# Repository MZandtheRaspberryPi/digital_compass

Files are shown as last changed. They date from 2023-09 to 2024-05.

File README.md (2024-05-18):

# digital_compass
Firmware, cad, and documentation for my digital compass project. This is a project where I designed, manufactured, and coded a digital compass that uses an inertial measurement unit (IMU) to estimate orientation in 3d-space. I implemented an extended kalman filter to (EKF) to do the estimation. A video explanation is available [here](https://www.youtube.com/shorts/Pg_2u4VAHLg) and a video demo is available [here](https://www.youtube.com/shorts/pv6mBfAY-nU).  

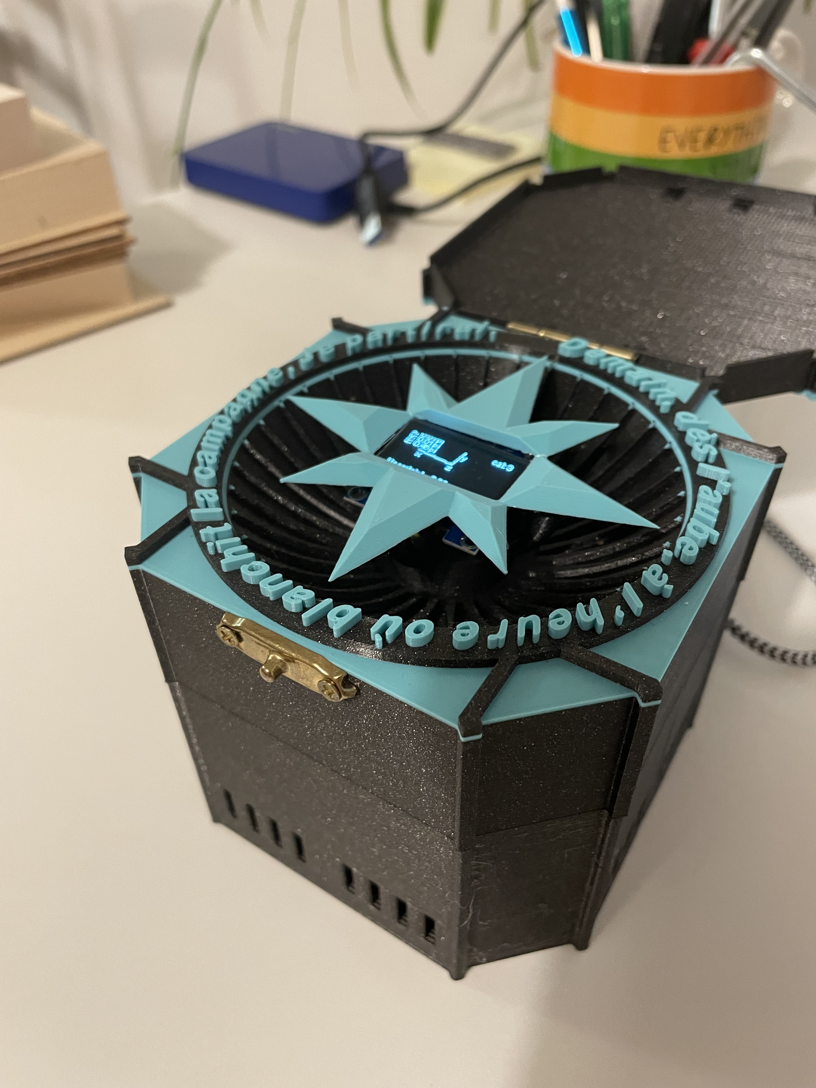
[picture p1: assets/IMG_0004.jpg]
compass_pic

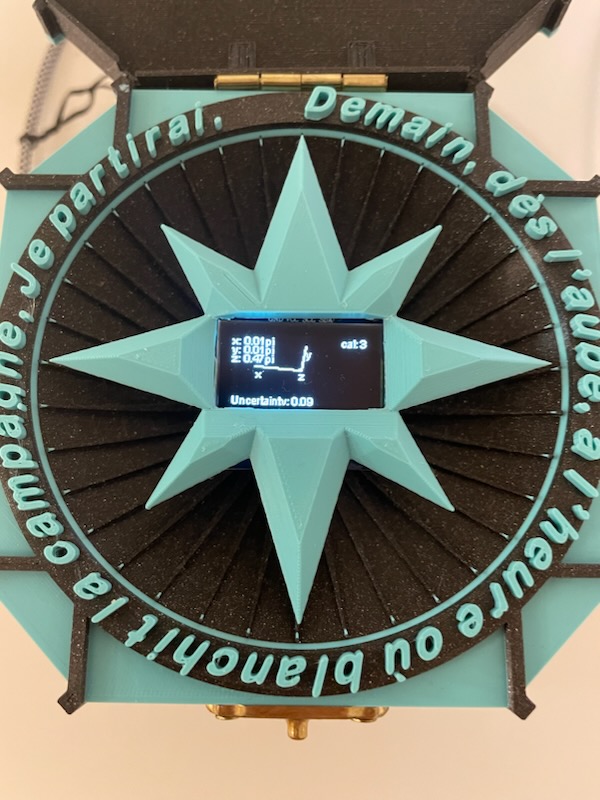
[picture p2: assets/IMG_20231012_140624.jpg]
compass_pic_2
  
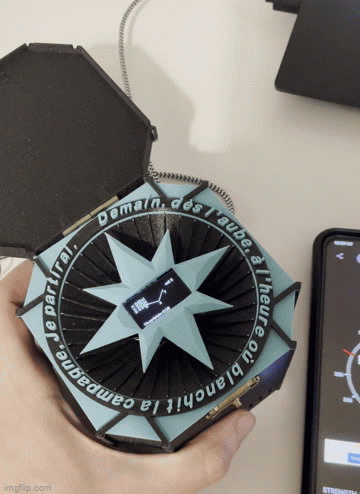
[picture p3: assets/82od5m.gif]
compass_demo
  

### Software  
On the software side I separated the project broadly into 3 components:  
* publishing the measurements from the sensor
* estimating orientation from the measurements
* visualizing the orientation  
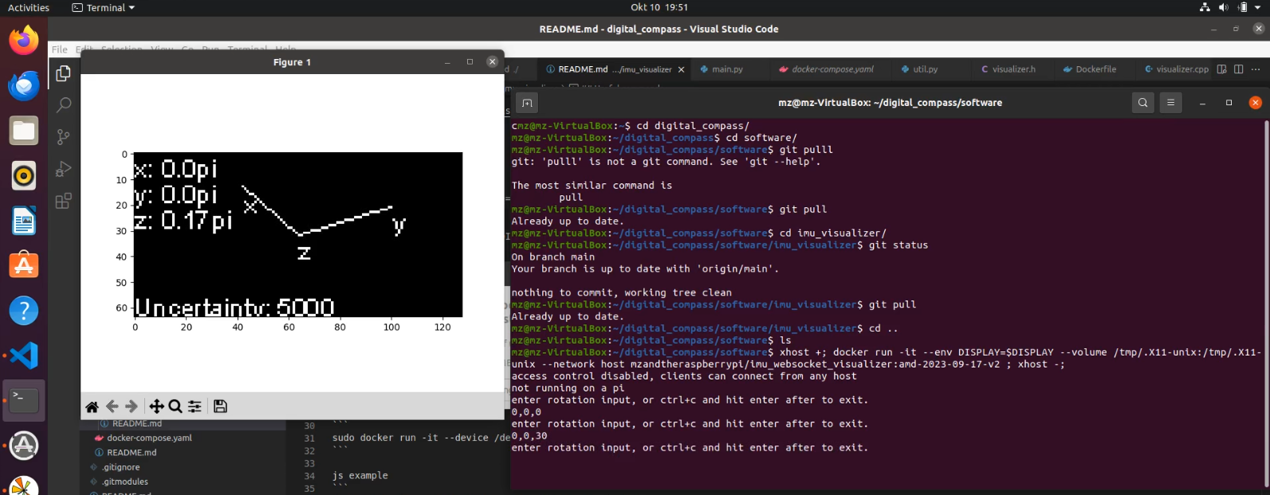
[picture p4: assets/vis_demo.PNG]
visualizer_demo


Design considerations:
* modular.
* shared libraries for websockets and message serialization.
* mainly c++.
* for matrix operations compile time checking of dimensions.
* only recreate the wheel for the filter algorithm, for the rest use libraries.
* for filter algorithm, make it possible to try different system models (expanding state matrix to estimate position for example) as well as different filter algorithms (UKF, particle filter, for example). Enter templates.  

To help keep things modular I used docker where each of the 3 components ran in a docker container. They talked to each other through websockets and messages serialized using Google's protobuffer. I used mainly CMake as a build system.  

You can run the package by navigating to the software sub directory and using docker compose to launch the compass.  

On libraries I created:  
* imu_broadcaster -- a repo that talks to the sensor and publishes calibration information, bosch's estimates of orientation, linear acceleration, angular acceleration, magnetic vector, timestamps, and more [here](https://github.com/MZandtheRaspberryPi?tab=repositories).
* imu_filter_cpp -- a repo that implements the system model and an Extended Kalman Filter to estimate orientation from the sensor data and publishes this onward [here](https://github.com/MZandtheRaspberryPi/imu_filter_cpp).
* imu_visualizer -- a repo that listens to our orientation estimate and visualies this on the screen inside of the compass. It projects the 3d coordinate frame onto the 2d screen [here](https://github.com/MZandtheRaspberryPi/imu_visualizer).
* imu_websockets -- a repo that contains wrappers for the third party websocketpp library to easily broadcast and listen, as well as our protobuffer message files and generated libraries [here](https://github.com/MZandtheRaspberryPi/imu_websockets).  
* imu_filter -- a repo to use imu data and ground truth data [[2]](#2) and simulate our model as a proof of concept [here](https://github.com/MZandtheRaspberryPi/imu_filter).
* Adafruit_BNO055 -- a repo I forked from Adafruit's implementation (see below in 3rd party library section) but heavily modified to build using CMake and to run on a raspberry pi instead of an Arduino board [here](https://github.com/MZandtheRaspberryPi/Adafruit_BNO055).  
* imu_adafruit_testing -- a repo to do initial tests that we can get sensor data in docker using some adafruit libraries and using 2 sensors [here](https://github.com/MZandtheRaspberryPi/imu_adafruit_testing).

On third party libraries used:  
* the Eigen3 Library and their Eigen::Matrix class to do linear algebra [here](https://eigen.tuxfamily.org/index.php?title=Main_Page).
* the websocketspp library to setup and send data using websockets [here](https://eigen.tuxfamily.org/index.php?title=Main_Page).
* adafruit libraries to talk to the Adafruit bno055 sensor dev board I used, namely the Adafruit_BNO055 library [here](https://github.com/adafruit/Adafruit_BNO055), though I heavily modified it to run on a raspberry pi instead of an Arduino board. Also the adafruit-circuitpython-ssd1306 library to write to the oled.
* the libi2c-dev ubuntu library to talk to my sensor [here](https://packages.ubuntu.com/jammy/libi2c-dev).

To run this, I used the docker compose file [here](software/docker-compose.yaml).  
```
docker compose up
```

Or you could add something like the below to your cronjobs:
```
@reboot sleep 30; /usr/bin/docker compose -f /home/mikey/digital_compass/software/docker-compose.yaml up
```

### Design and Manufacturing

I designed the compass using Fusion 360 to look nice, be easily be assembled and disassembled, and be 3d printable. You can find design files in the cad_and_ecad folder.  

Here are some renders I made using Fusion 360 of the CAD:  

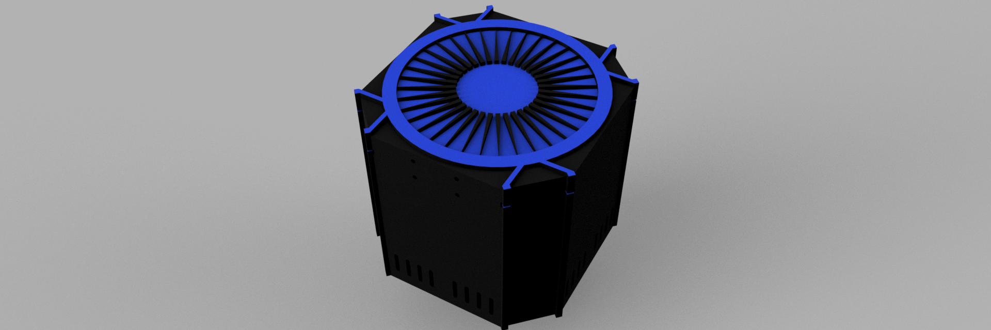
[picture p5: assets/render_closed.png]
body_render_closed


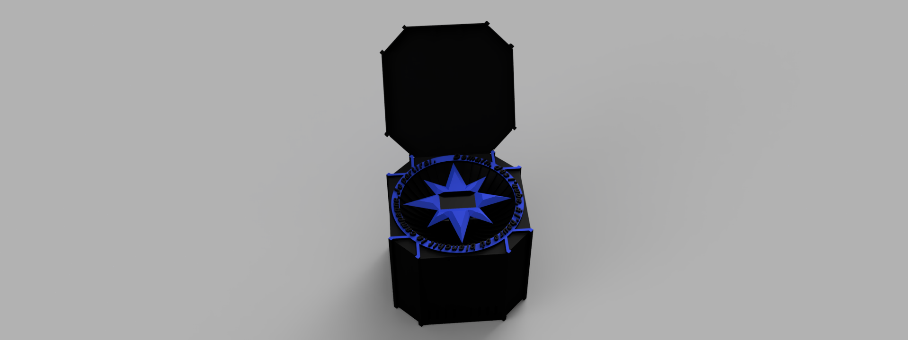
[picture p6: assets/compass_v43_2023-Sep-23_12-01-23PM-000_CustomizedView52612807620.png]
body_render


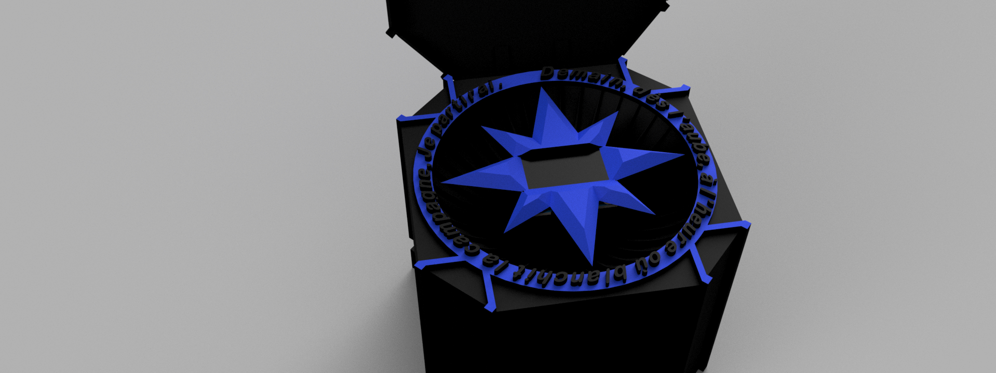
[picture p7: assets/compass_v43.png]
body_render_zoomed
  

The design uses threaded inserts to make it easy to assemble and take apart. It also uses a metal brass hinge for the top cover.  

One fun bit was trying to design a part to hold the screen. I wanted a super low profile, and so came up with a design inspired by an alien octopus grabbing the screen cover in a couple places with tentacle arms.  
screen_cover_1
screen_cover

I also ended up desiging a custom printed circuit board to simplify wiring. Before the custom PCB:  

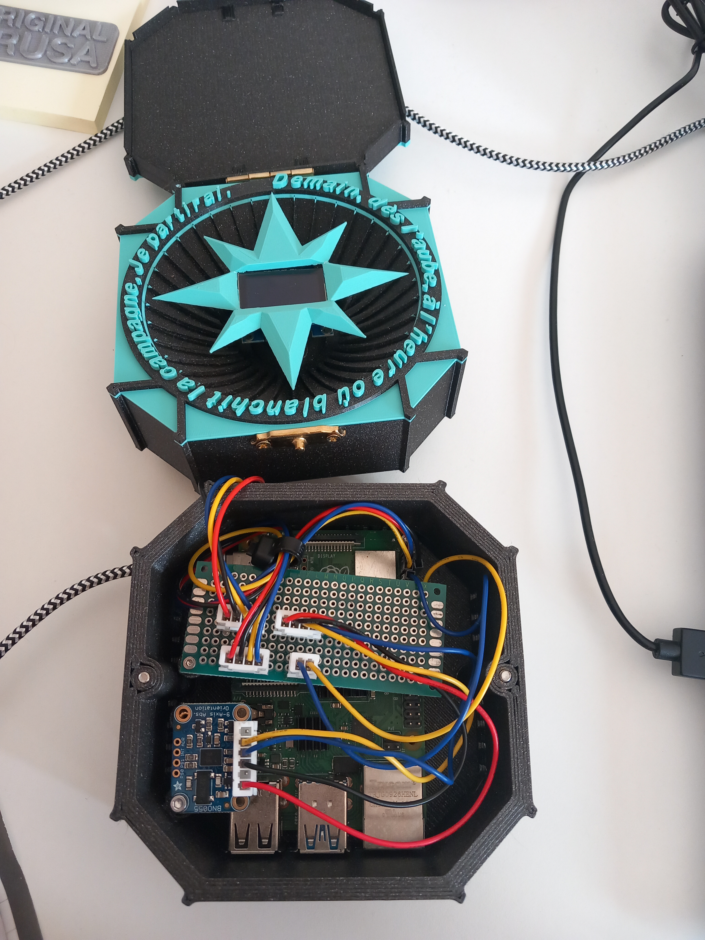
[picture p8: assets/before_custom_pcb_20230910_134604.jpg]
  

And after:  
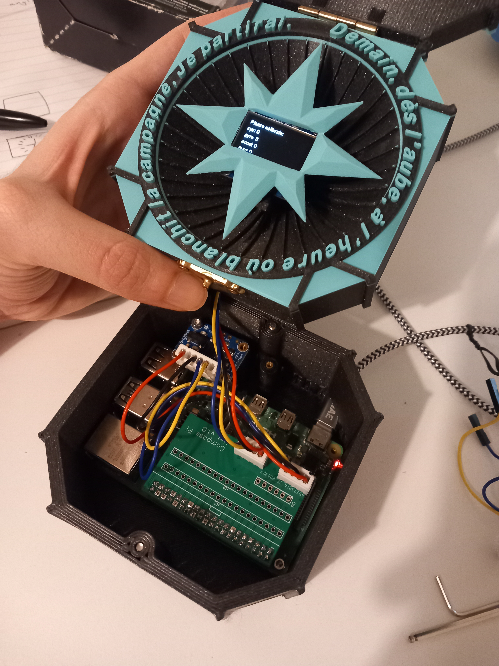
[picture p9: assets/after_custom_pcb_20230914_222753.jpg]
  

On the 3d Printing I used multi-color printing by doing a color change at a certain layer. With this I was able to get accent colors I quite liked.

### Maths
A big part of this project was modelling a system that could take measurements from an inertial measurement unit including angular rotation, linear acceleration, and magnetic vector, and estimate orientation. For this, I implemented a model from a 2020 paper by Saito et al, [[1]](#1),  with minimal tweaks. This was actually the first thing I did in this project, where I worked in simulation for some time till I thought I could pull it off in real life. You can see more details in the maths subdirectory and the .pdf write up in that directory [here](https://github.com/MZandtheRaspberryPi/imu_filter/blob/main/write_up/project_writeup.pdf), but briefly I found some data from an IMU including ground truth data [here](https://github.com/agnieszkaszczesna/RepoIMU) [[2]](#2) and played this back in simulation and implemented a model to try and match the ground truth data given sensor measurements. You can see this simulation output below, where it is not perfect and it jumps sometimes, but it is not worlds apart either:  
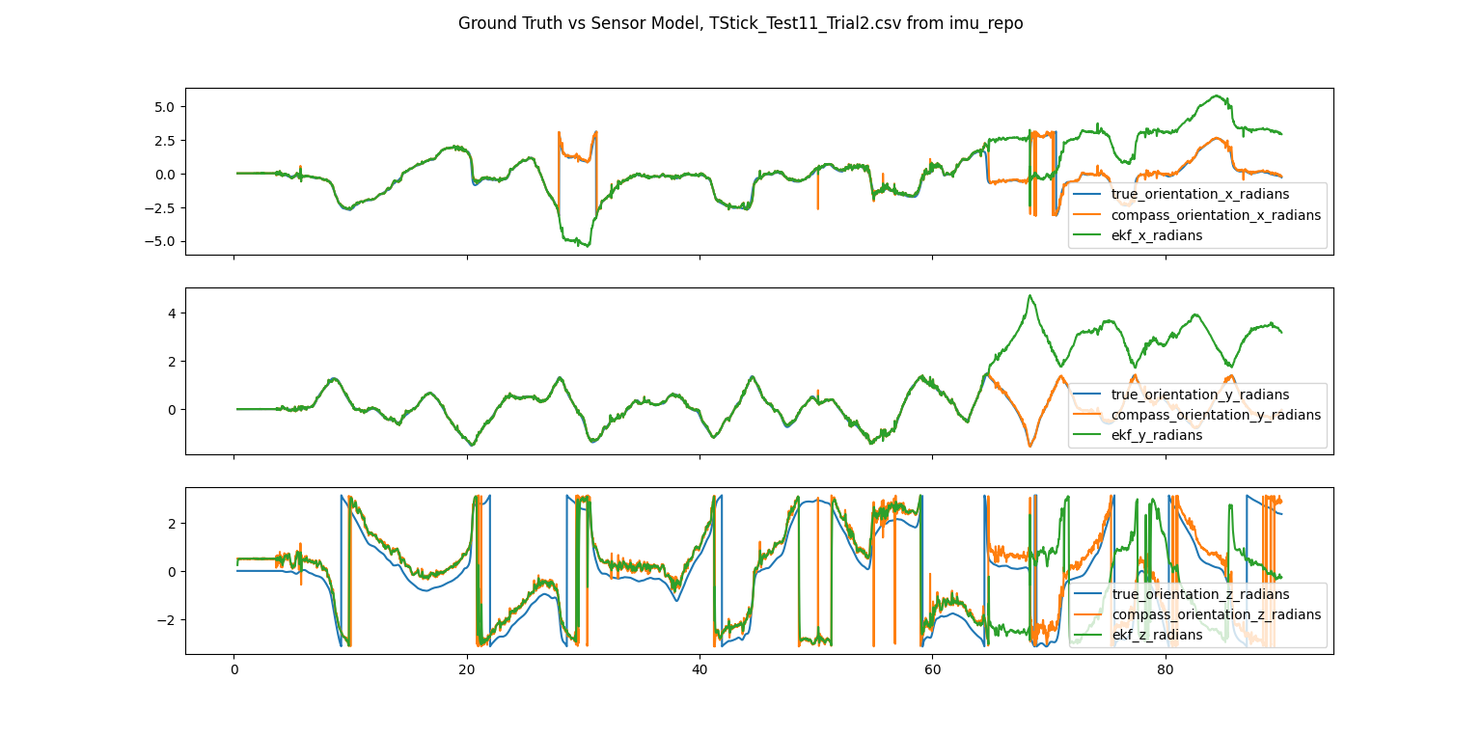
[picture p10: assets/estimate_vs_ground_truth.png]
simulation
  

I use an Extended Kalman Filter to model the system and make estimates of my state, which is x rotation, y rotation, z rotation.

To transition from one state at time t=0 to another state at time t=1, see the below. This looks complicated, but really we are taking our prior orientation, and adding the change in orientation to it. We take the angular rotation from our gyroscope, rotate it into our world frame, and then multiply by change in time and add it to our prior estimate:  
transition_state  

Our sensor model looks like the below. We have the yaw as calculated from our magnetometer, and then we also have our expected acceleration assuming 0 linear acceleration on the robot, ie just gravity. See [[1]](#1) for detail or the maths subfolder and its repo where a paper is included:  
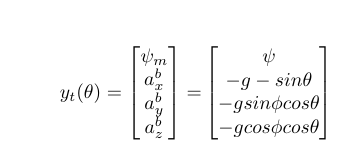
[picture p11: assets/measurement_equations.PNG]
sensor_model


From here we take the jacobians of each to use in the EKF model, as the system is non-linear we linearize using the jacobians.  

### Bibliography
<a id="1">[1]</a> 
Saito, A., Kizawa, S., Kobayashi, Y. et al. Pose estimation by extended Kalman filter using noise covariance matrices based on sensor output. Robomech J 7, 36 (2020). https://doi.org/10.1186/s40648-020-00185-y

<a id="2">[2]</a>
Szczęsna, A., Skurowski, P., Pruszowski, P., Pęszor, D., Paszkuta, M., & Wojciechowski, K. (2016, September). Reference data set for accuracy evaluation of orientation estimation algorithms for inertial motion capture systems. In International Conference on Computer Vision and Graphics (pp. 509-520). Springer, Cham.

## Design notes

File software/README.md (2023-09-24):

### Pi Setup
I used Ubuntu 22.04. I flashed an image using raspberry pi imager, which let me configure user and wifi. Then, I did:

```
ssh-keygen # generate and copy key to github
curl -fsSL https://get.docker.com -o get-docker.sh
sudo sh ./get-docker.sh --dry-run # remove dry run flag when want to run
sudo usermod -aG docker $USER
sudo reboot

docker run hello-world
```

```
git clone git@github.com:MZandtheRaspberryPi/digital_compass.git --recurse-submodules
```

### Calibrating

Datasheet [here](https://cdn-shop.adafruit.com/datasheets/BST_BNO055_DS000_12.pdf) has section 3.10 on calibrating.

For accelerometer, "6 different stable positions for a period of few seconds to allow the accelerometer to calibrate."

For gyro: "Place the device in a single stable position for a period of few seconds to allow the gyroscope to calibrate."

For mag: "the steps mentioned below are to calibrate the magnetometer for hard-iron distortion (...) Compass, M4G & NDOF_FMC_OFF: Make some random movements (for example: writing the number ‘8’ on air) until the
CALIB_STAT register indicates fully calibrated."

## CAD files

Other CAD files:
cad_and_ecad/compass_rose v25.f3z

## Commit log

2023-08-19 adding initial i2c tests
2023-08-20 adding results of i2c test
2023-08-20 updating notes on alternate i2c chip
2023-08-20 adding i2c 3
2023-08-23 adding circuit python test
2023-09-03 removing i2c test dir
2023-09-10 adding latest imu broadcaster
2023-09-10 updating filter to latest version
2023-09-10 updating to latest imu_vis
2023-09-17 updating to latest filter with better estimates
2023-09-17 adding calibration notes
2023-09-24 adding some documentation
    [compass_rose v25.f3z]
2023-09-24 removing test circuit python
2023-10-15 updating filter to latest
2023-10-15 updating to latest filter
